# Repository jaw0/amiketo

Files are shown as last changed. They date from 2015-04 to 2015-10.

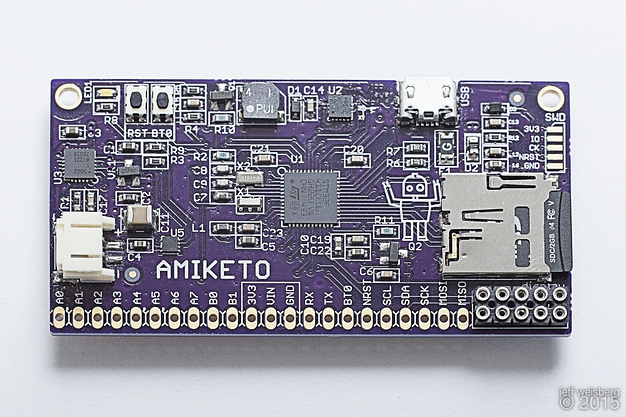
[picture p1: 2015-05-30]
img/64c068820_6_amiketo_top.jpg

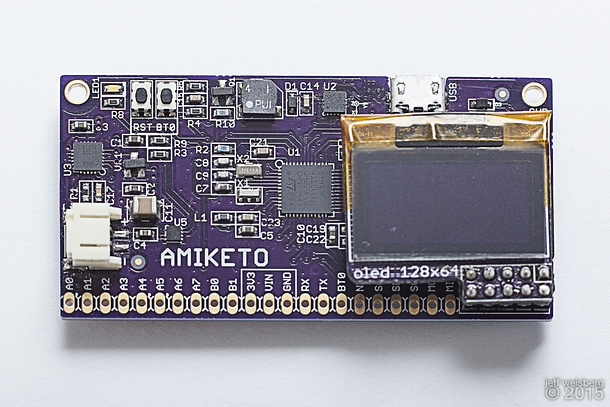
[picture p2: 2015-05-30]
img/64c068822_6_amiketo_oled.jpg

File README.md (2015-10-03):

tiny, low power, ARM-based board

* 35mm x 69mm
* breadboard friendly pinout

hardware:

* STM32F411
  * 96 MHz Cortex M4F
  * 100 uA / MHz
  * 10 analog inputs
  * 10 digital inputs
  * 10 digital outputs
  *  8 PWM outputs
  * i2c, spi, uart, usb
  * real-time-clock
  * board compat with most 48pin STM32s (eg. F103, L152, L072)
* micro SD card
* audio speaker
* OLED display
* AD5062 programmable battery charger
  * configurable charge current
  * configurable USB current
  * configurable charging parameters
* MAX17048 battery fuel gauge

software:

* can (will eventually) run open-source:
  * python
  * javascript
  * mbed
  * .NET
  * arduino
* comes with battery charger + data-logger
* write your own code

other:

* RoHS, lead-free
* fat-free, sugar-free, gluten-free

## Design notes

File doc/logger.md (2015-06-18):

## features

* depending on the config, logging 2 analog channels at audio rates is possible
* can programmatically control whether to log or not log
* wide variety of file formats
* log analog or digital values

## configuring the data logger

`logger_logfile = <filename>` - set the output file name

`logger_values <list of pins>` - specify which pins to log

`logger_format <format>` - specify the data file format. currently supported:
* csv   - comma separated values
* json  - newline delimited json
* xml   - record oriented, partial xml (missing outer wrapper)
* raw   - raw 16bit little-endian values
* sln   - raw signed-linear 16bit little-endian values
* alaw  - 8 bit a-law compressed
* xlaw  - 8 bit unsigned 3e/5m compressed
* bits  - raw 1 bit per value, for digital inputs
* tca   - a-law with timestamps + silence suppression

`logger_rate <rate>` - specify the logging sampling rate.
depending on your config, you may be able to go from
usecs to years.
suffix with `u` for microseconds, `m` for milliseconds,
`M` for minutes, `H` for hours, `D` for days.

`logger_lowpower = <0,1>` if set to 1, system will enter low-power standby mode
at slow sampling rates

`logger_script = <filename>` - specify a script to run at each sampling. script
can choose to log or not log the samples, or perform other actions.

`logger_autostart = <0,1>` - start the logger automaitically at boot

`logger_start` - manually start the logger

`logger_stop`  - stop the logger

`logger_reload` - reload logging parameters

`logger_rotate` - rotate the log file

## example
```
pinmode A0 adc
pinmode A1 adc
logger_values A0 A1
logger_rate 1m
logger_logfile = data.log
logger_format xml
logger_start
```

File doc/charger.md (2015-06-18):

## configuring the battery charger

`input_current <mA>` - set the maximum USB input current.
can be set from 100 to 2100 millamps. you should not set this
higher than 500 millamps unless you are supplying
power via a non-USB source via the Vin pin.

`charge_current <mA>` - set the battery charging current.
can be set from 50 to 1300 milliamps. set this to the value
recommended by your battery manufacturer, setting a higher value
may damage the battery.

`charge_status` - show the current charging status

## example
```
input_current 500
charge_current 200
```

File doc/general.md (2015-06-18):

## configuring

* connect to the board using a terminal emulator + either the USB port or via a FT232 (or similar) on the RX/TX pins
* enter commands
* enter `save` to save the config to the SD card
* `show run` will show the current running config
* `more config.rc` will show the saved config
* `help` or `help command` for help

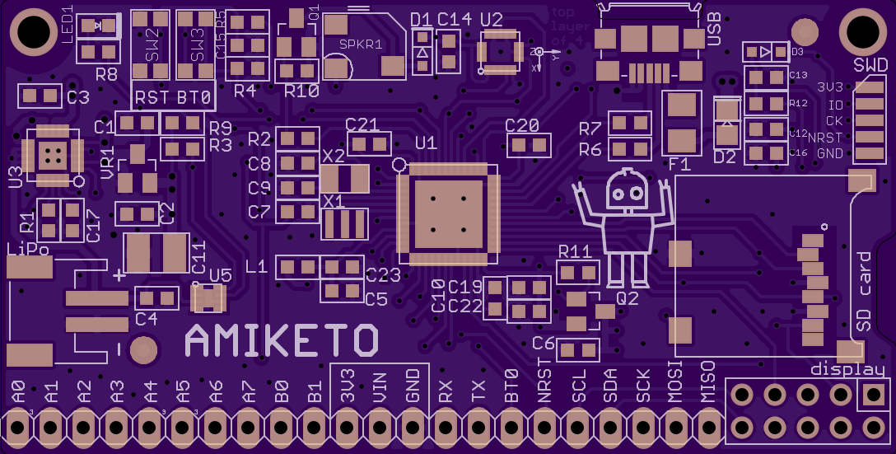
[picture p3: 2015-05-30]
img/pcb-top-oshpark.png

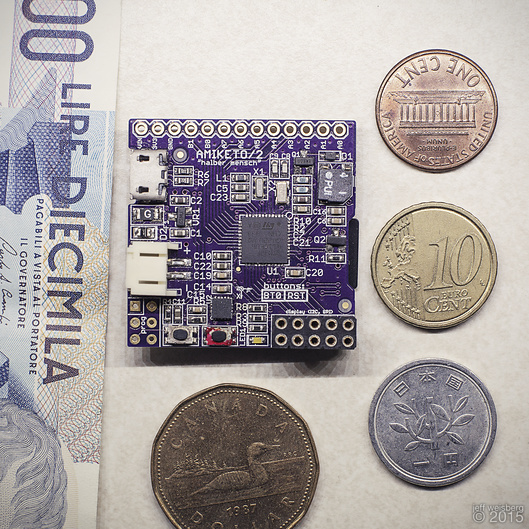
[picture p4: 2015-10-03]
img/money_for_scale.jpg

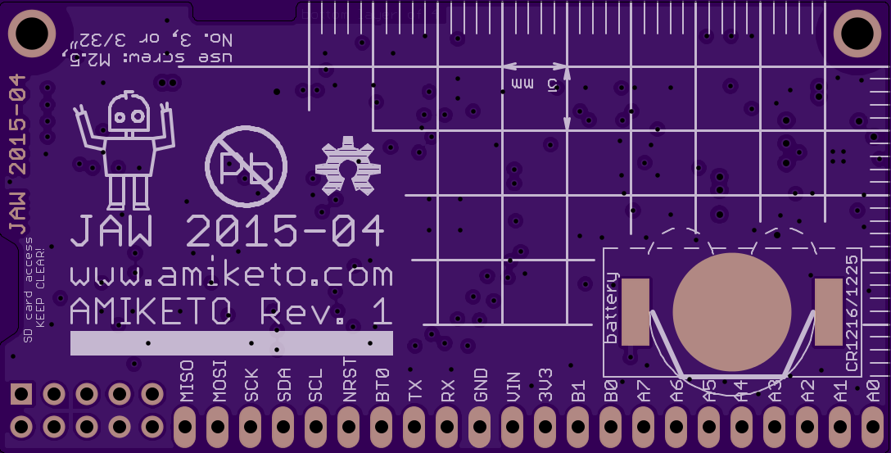
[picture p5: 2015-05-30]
img/pcb-bottom-oshpark.png

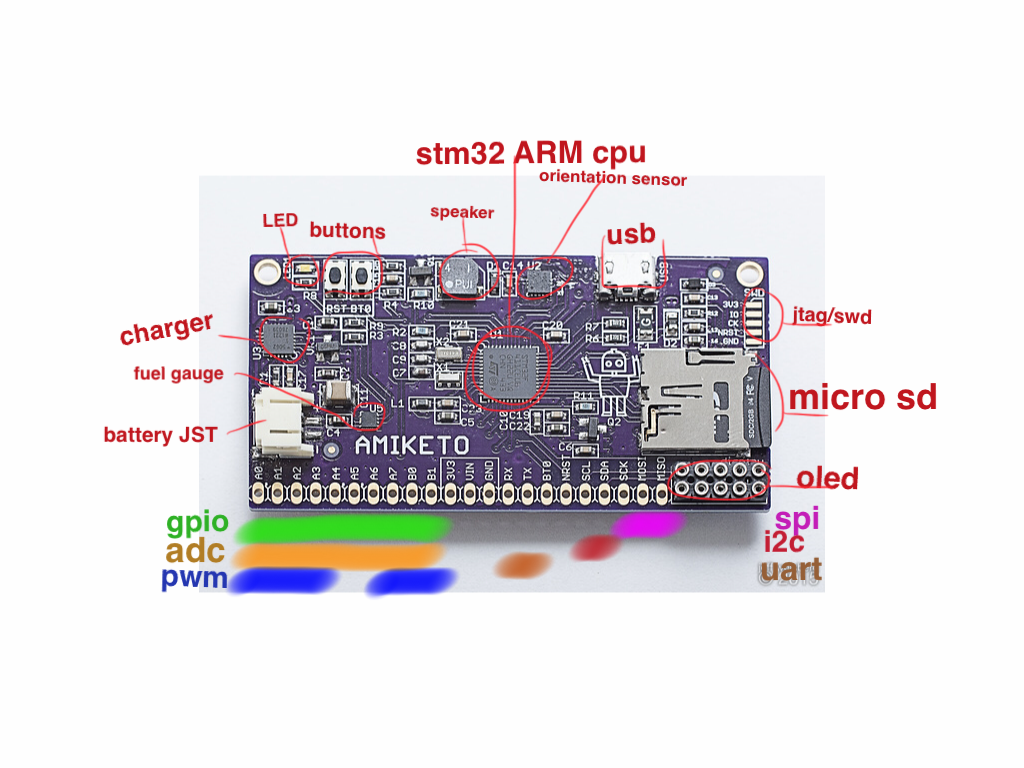
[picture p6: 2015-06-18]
img/board-labeled.png

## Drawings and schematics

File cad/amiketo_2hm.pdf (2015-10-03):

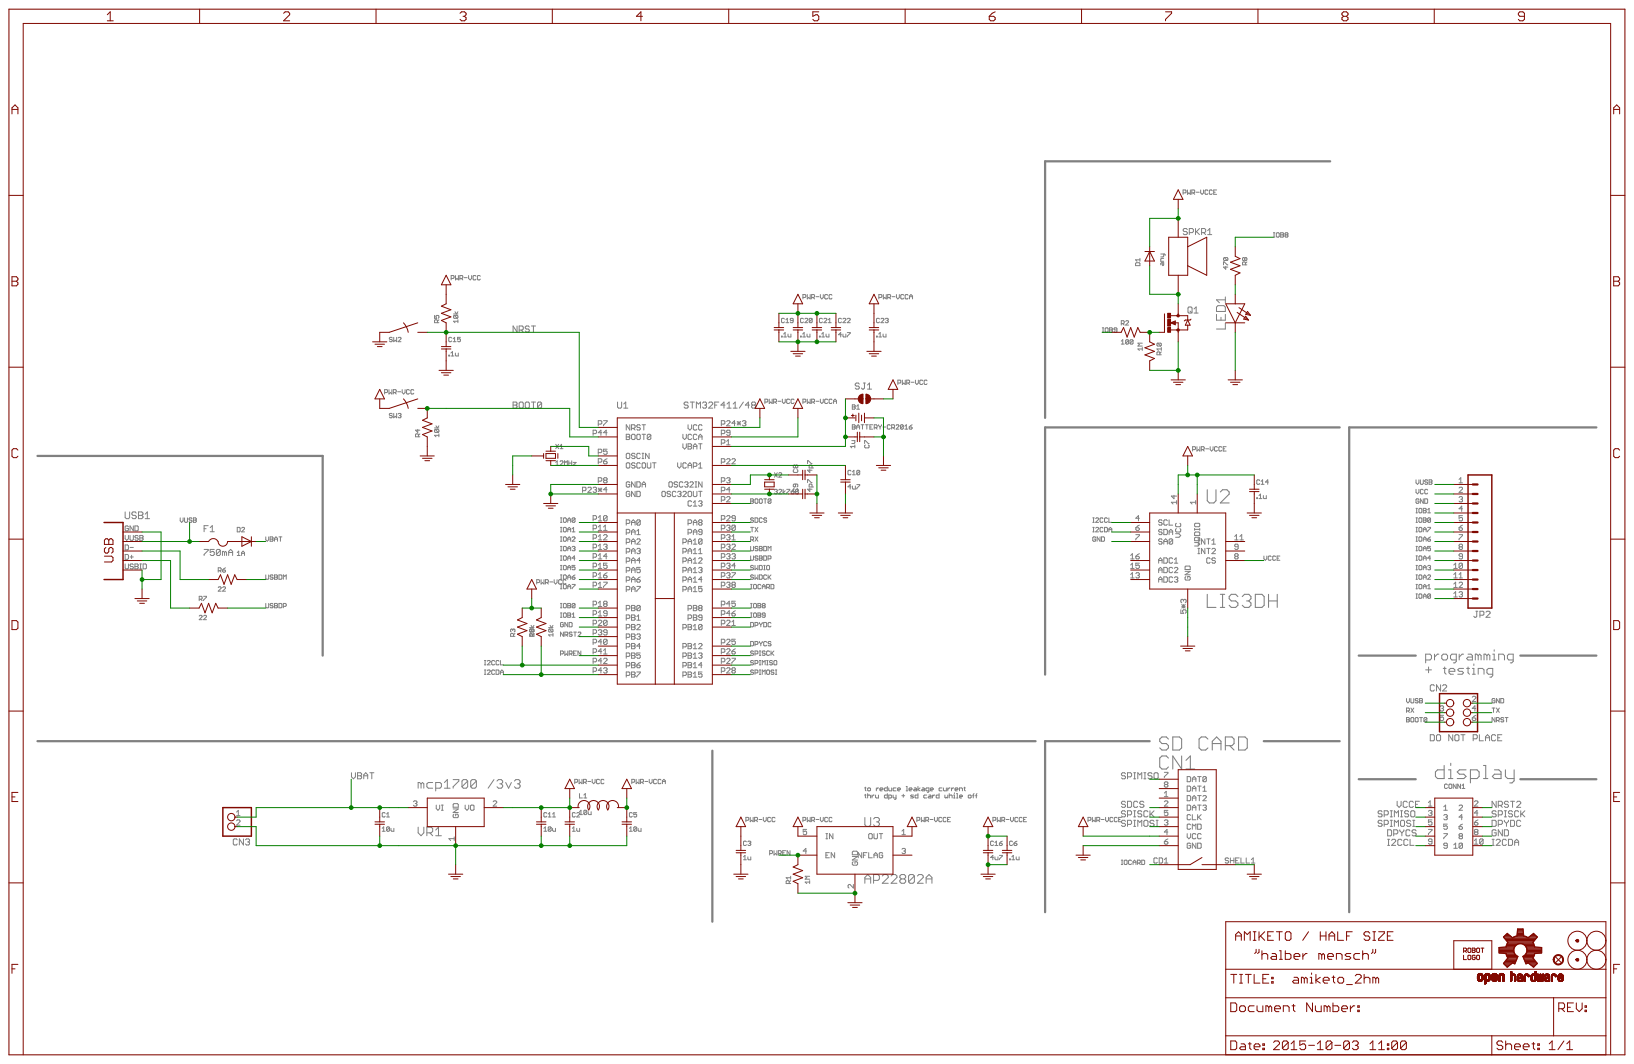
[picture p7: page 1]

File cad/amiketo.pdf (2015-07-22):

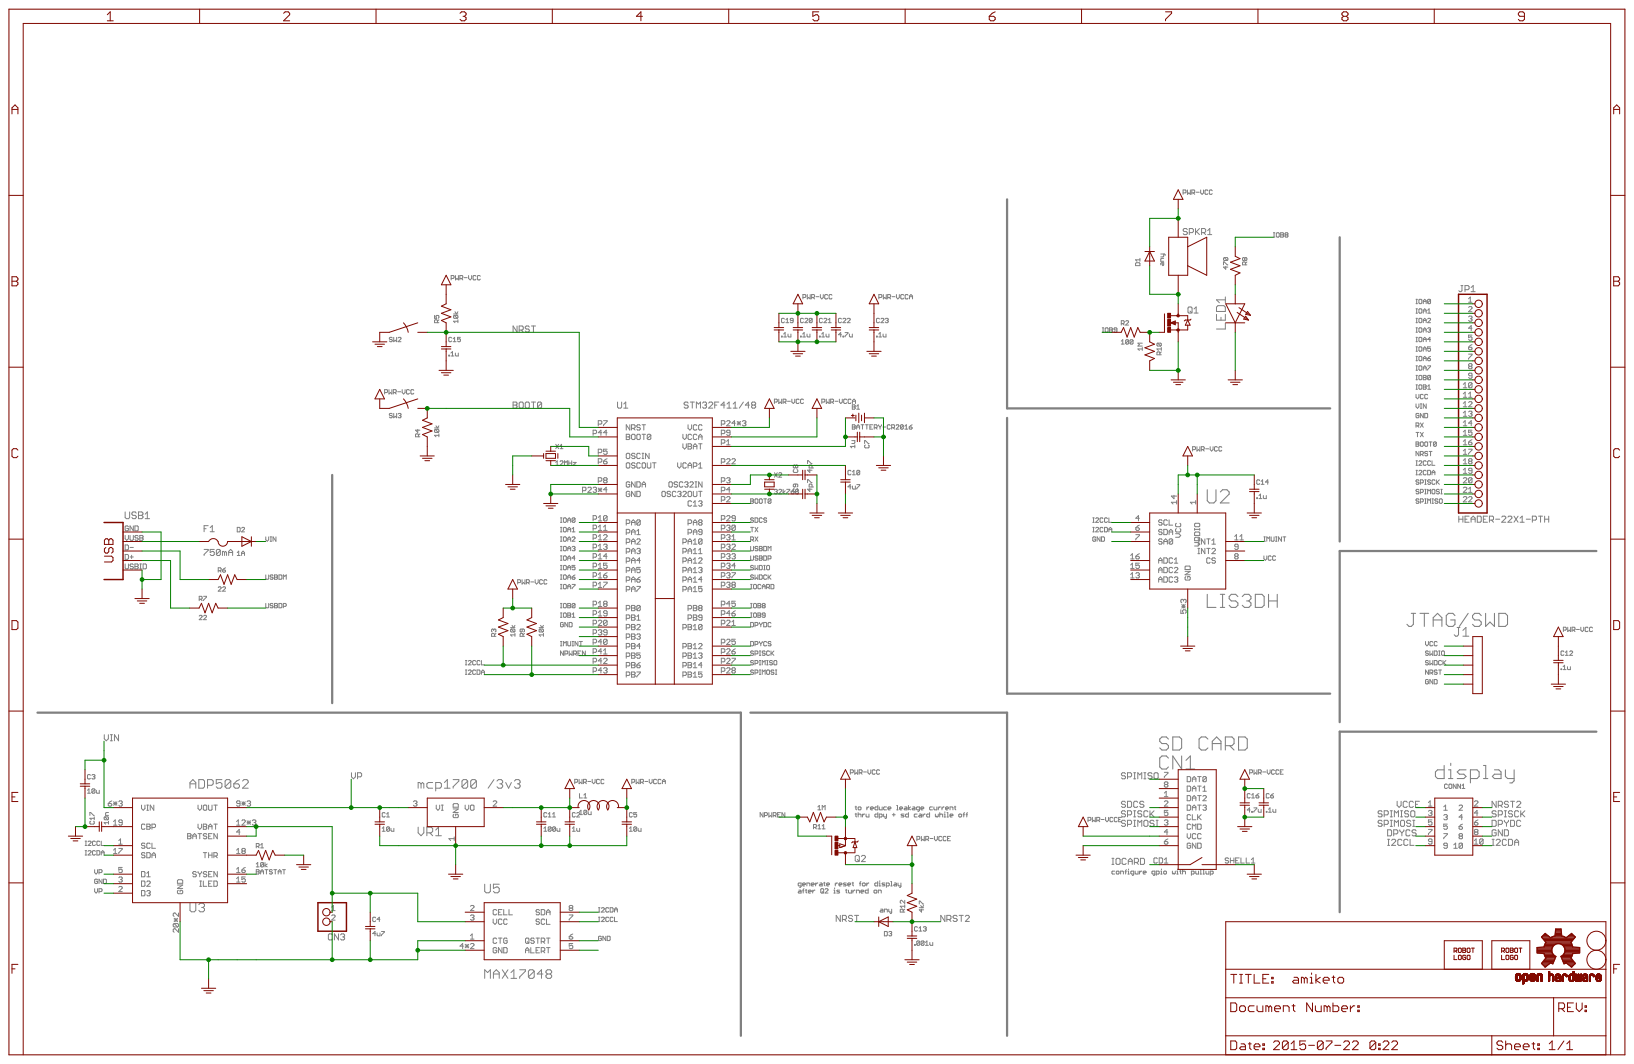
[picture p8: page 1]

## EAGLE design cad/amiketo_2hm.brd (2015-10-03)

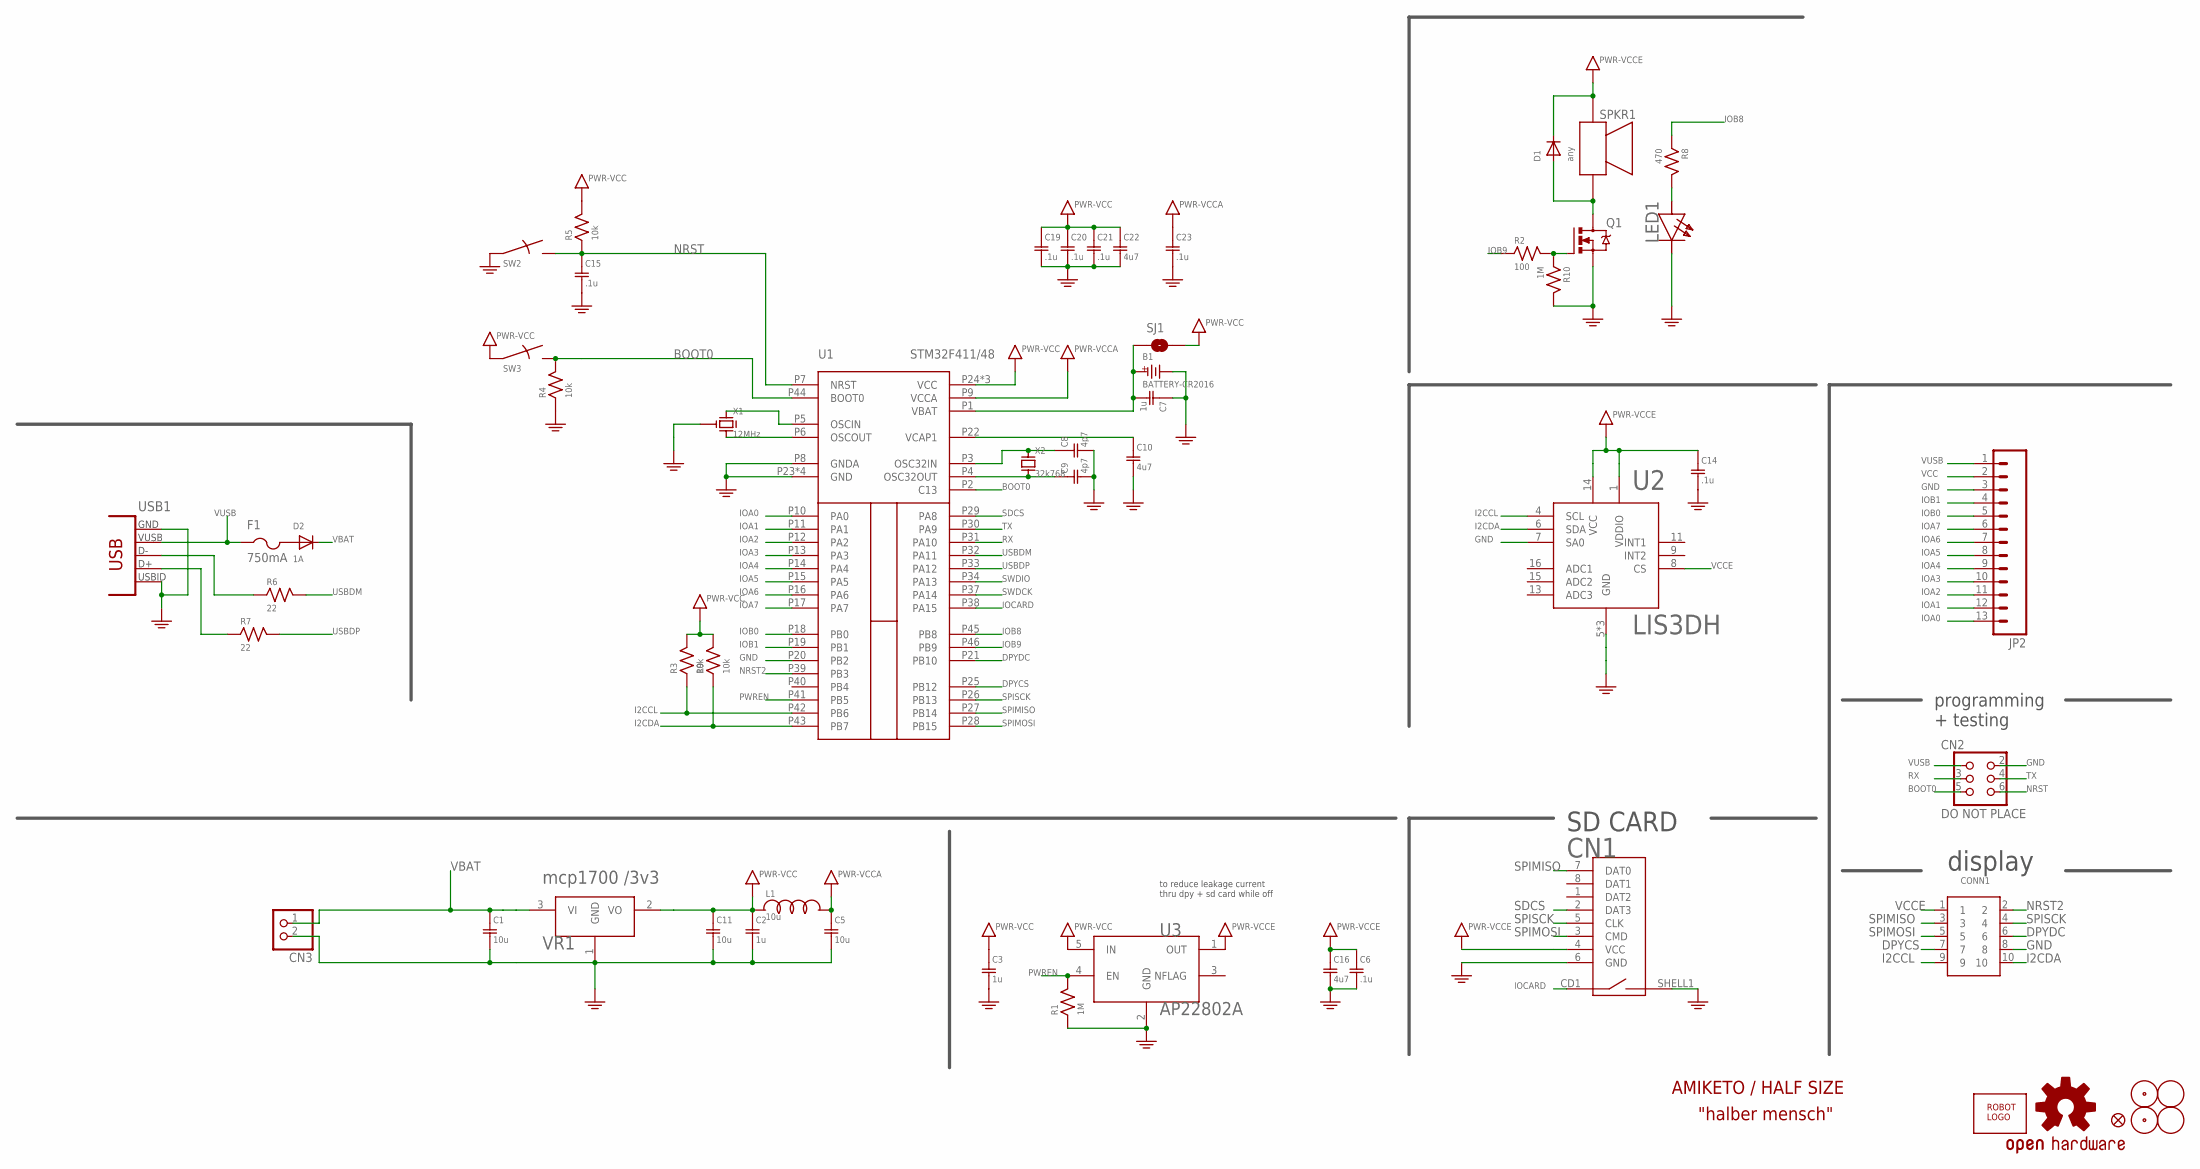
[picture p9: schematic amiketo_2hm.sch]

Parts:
B1: BATTERY-CR2016; CR1216
C1, C5, C11: 10u; SMD0603
C2, C3, C7: 1u; SMD0603
C6, C14, C15, C19, C20, C21, C23: .1u; SMD0603
C8, C9: 4p7; SMD0603
C10, C16, C22: 4u7; SMD0603
CN1: MICROSD-EJECT; MICROSD/EJECTOR
CN2: DO NOT PLACE; HEADER-3X2-POGO
CN3: JST_2PIN-SMT-RA; JST-PH-2-SMT-RA
CONN1: HEADER-5X2-PTH
D1: any; SMD0805D
D2: 1A; SMD0805D
F1: 750mA; SMD1206
JP2: M13; 1X13
L1: 10u; SMD0603
LED1: white; SMD0603D
LOGO1: OSHW-LOGOM; OSHW-LOGO-M
Q1: IRLML6344TRPBF; SOT-23
R1, R10: 1M; SMD0603
R2: 100; SMD0603
R3, R4, R5, R9: 10k; SMD0603
R6, R7: 22; SMD0603
R8: 470; SMD0603
SJ1: JUMPER-PAD-2-NOYES_SILK; PAD-JUMPER-2-NO_YES_SILK
SPKR1: PUI-5040; PUI-0540
SW2, SW3: SWITCHKMR211; KMR211
U1: STM32F411/48; UQPFN48
U2: LIS3DH; LGA16A
U3: AP22802A; SOT-23-5
U$1, U$5: FIDUCIAL
U$2, U$3: FIDUCIAL; FIDUCIAL_1MM
U$4: ROBOTMAN-LOGO2
U$6: FIDUCIALUFIDUCIAL; MICRO-FIDUCIAL
USB1: CON-USB-F-MICRO-B; CONN_USB_MICRO-B
VR1: mcp1700 /3v3; SOT-23-3
X1: 12MHz; RESONATOR-CSTCE
X2: 32k768; XTAL-32X15

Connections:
BOOT0: CN2.5, R4.2, SW3.2, SW3.4, U1.P2 (C13), U1.P44 (BOOT0)
DPYCS: CONN1.7, U1.P25 (PB12)
DPYDC: CONN1.6, U1.P21 (PB10)
GND: B1.MINUS (M), C1.2, C2.2, C3.2, C5.2, C6.2, C7.1, C8.2, C9.2, C10.2, C11.2, C14.2, C15.2, C16.2, C19.2, C20.2, C21.2, C22.2, C23.2, CN1.6 (GND), CN1.SHELL1 (SW2), CN2.2, CN3.2 (1), CONN1.8, JP2.3, LED1.C, Q1.2 (S), R1.1, R4.1, R10.2, SW2.1, SW2.3, U1.P8 (GNDA), U1.P20 (PB2), U1.P23 (GND), U1.P35 (GND), U1.P47 (GND), U1.PAD (GND), U2.5 (GND), U2.7 (SA0), U2.10 (GND), U2.12 (GND), U3.2 (GND), USB1.P4 (USBID), USB1.P5 (GND), VR1.1 (GND), X1.2 (G)
I2CCL: CONN1.9, R3.1, U1.P42 (PB6), U2.4 (SCL)
I2CDA: CONN1.10, R9.1, U1.P43 (PB7), U2.6 (SDA)
IOA0: JP2.13, U1.P10 (PA0)
IOA1: JP2.12, U1.P11 (PA1)
IOA2: JP2.11, U1.P12 (PA2)
IOA3: JP2.10, U1.P13 (PA3)
IOA4: JP2.9, U1.P14 (PA4)
IOA5: JP2.8, U1.P15 (PA5)
IOA6: JP2.7, U1.P16 (PA6)
IOA7: JP2.6, U1.P17 (PA7)
IOB0: JP2.5, U1.P18 (PB0)
IOB1: JP2.4, U1.P19 (PB1)
IOB8: R8.1, U1.P45 (PB8)
IOB9: R2.1, U1.P46 (PB9)
IOCARD: CN1.CD1 (SW1), U1.P38 (PA15)
unnamed: R6.1, USB1.P2 (D-)
unnamed: R7.1, USB1.P3 (D+)
unnamed: Q1.1 (G), R2.2, R10.1
unnamed: LED1.A, R8.2
unnamed: U1.P5 (OSCIN), X1.1 (X1)
unnamed: U1.P6 (OSCOUT), X1.3 (X2)
unnamed: D1.A, Q1.3 (D), SPKR1.P2
unnamed: C8.1, U1.P3 (OSC32IN), X2.P$1
unnamed: C9.1, U1.P4 (OSC32OUT), X2.P$2
unnamed: C10.1, U1.P22 (VCAP1)
unnamed: B1.PLUS1, B1.PLUS2, C7.2, SJ1.1, U1.P1 (VBAT)
unnamed: D2.A, F1.2
NRST: C15.1, CN2.6, R5.1, SW2.2, SW2.4, U1.P7 (NRST)
NRST2: CONN1.2, U1.P39 (PB3)
PWREN: R1.2, U1.P41 (PB5), U3.4 (EN)
RX: CN2.3, U1.P31 (PA10)
SDCS: CN1.2 (DAT3), U1.P29 (PA8)
SPIMISO: CN1.7 (DAT0), CONN1.3, U1.P27 (PB14)
SPIMOSI: CN1.3 (CMD), CONN1.5, U1.P28 (PB15)
SPISCK: CN1.5 (CLK), CONN1.4, U1.P26 (PB13)
SWDCK: U1.P37 (PA14)
SWDIO: U1.P34 (PA13)
TX: CN2.4, U1.P30 (PA9)
USBDM: R6.2, U1.P32 (PA11)
USBDP: R7.2, U1.P33 (PA12)
VBAT: C1.1, CN3.1 (2), D2.C, VR1.3 (VI)
VCC: C2.1, C3.1, C11.1, C19.1, C20.1, C21.1, C22.1, JP2.2, L1.1, R3.2, R5.2, R9.2, SJ1.2, SW3.1, SW3.3, U1.P24 (VCC), U1.P36 (VCC), U1.P48 (VCC), U3.5 (IN), VR1.2 (VO)
VCCA: C5.1, C23.1, L1.2, U1.P9 (VCCA)
VCCE: C6.1, C14.1, C16.1, CN1.4 (VCC), CONN1.1, D1.C, SPKR1.P1, U2.1 (VDDIO), U2.8 (CS), U2.14 (VCC), U3.1 (OUT)
VUSB: CN2.1, F1.1, JP2.1, USB1.P1 (VUSB)

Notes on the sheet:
SD CARD
display
to reduce leakage current thru dpy + sd card while off
programming + testing
AMIKETO / HALF SIZE
"halber mensch"

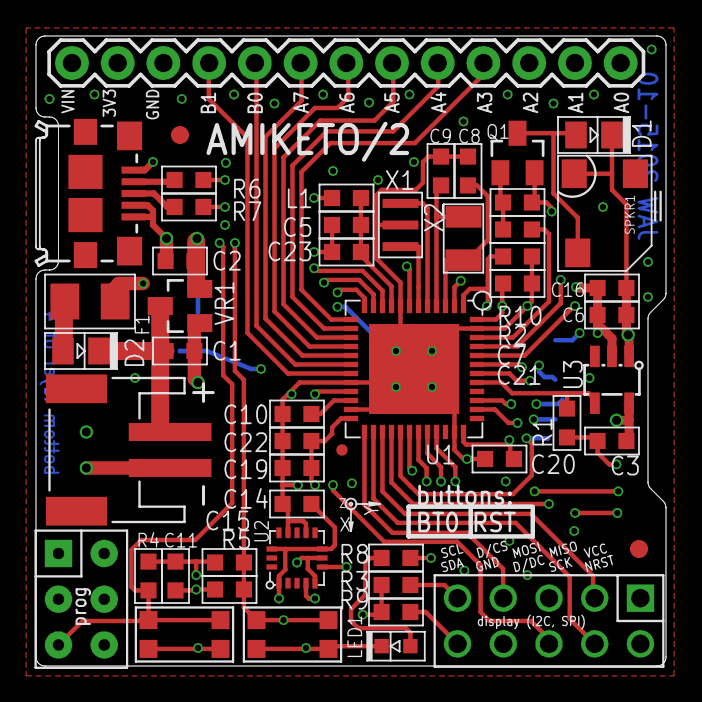
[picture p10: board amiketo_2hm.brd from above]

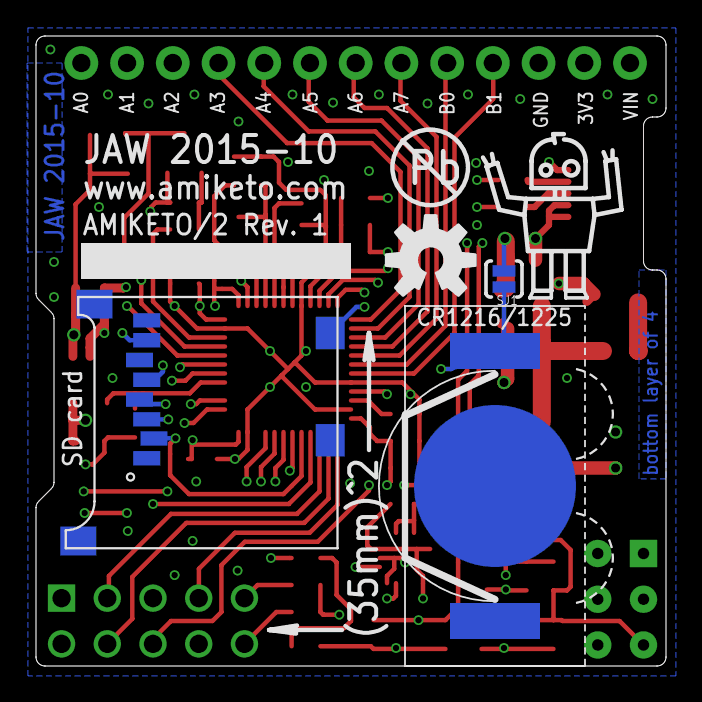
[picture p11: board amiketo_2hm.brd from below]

Board: 4 copper layers, 35.0 x 35.0 mm, 58 parts (7 on the bottom side), 47 nets.

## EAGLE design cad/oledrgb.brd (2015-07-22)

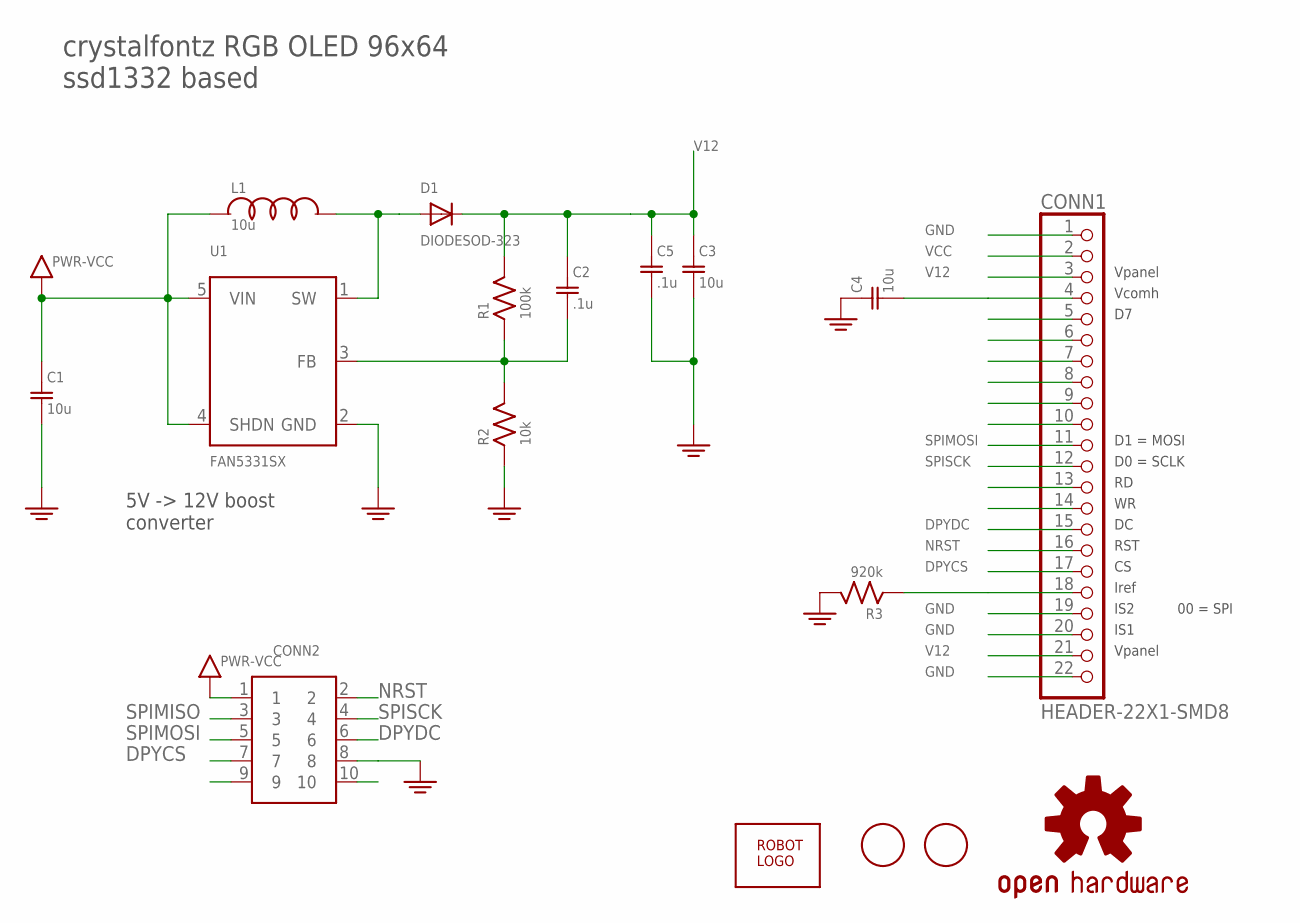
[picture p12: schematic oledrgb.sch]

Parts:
C1, C3, C4: 10u; SMD0603
C2, C5: .1u; SMD0603
CONN1: HEADER-22X1-SMD8
CONN2: HEADER-5X2-PTH
D1: DIODESOD-323; SOD-323
L1: 10u; SMD0603
LOGO1: OSHW-LOGOS; OSHW-LOGO-S
R1: 100k; SMD0603
R2: 10k; SMD0603
R3: 920k; SMD0603
U1: FAN5331SX; SOT23-5
U$1: ROBOTMAN-LOGO2
U$2, U$3: FIDUCIAL; FIDUCIAL_1MM

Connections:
DPYCS: CONN1.17, CONN2.7
DPYDC: CONN1.15, CONN2.6
GND: C1.2, C3.2, C4.1, C5.2, CONN1.1, CONN1.19, CONN1.20, CONN1.22, CONN2.8, R2.1, R3.2, U1.2 (GND)
unnamed: D1.A, L1.2, U1.1 (SW)
unnamed: C2.2, R1.1, R2.2, U1.3 (FB)
unnamed: C4.2, CONN1.4
unnamed: CONN1.18, R3.1
NRST: CONN1.16, CONN2.2
SPIMISO: CONN2.3
SPIMOSI: CONN1.11, CONN2.5
SPISCK: CONN1.12, CONN2.4
V12: C2.1, C3.1, C5.1, CONN1.3, CONN1.21, D1.C, R1.2
VCC: C1.1, CONN1.2, CONN2.1, L1.1, U1.4 (SHDN), U1.5 (VIN)

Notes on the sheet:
Vpanel
Vcomh
D0 = SCLK
D1 = MOSI
RST
Iref
IS2
IS1
00 = SPI
crystalfontz RGB OLED 96x64 ssd1332 based
5V -> 12V boost converter

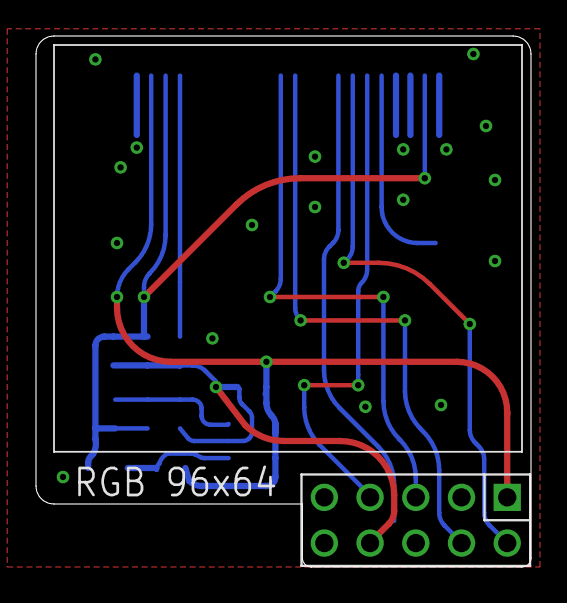
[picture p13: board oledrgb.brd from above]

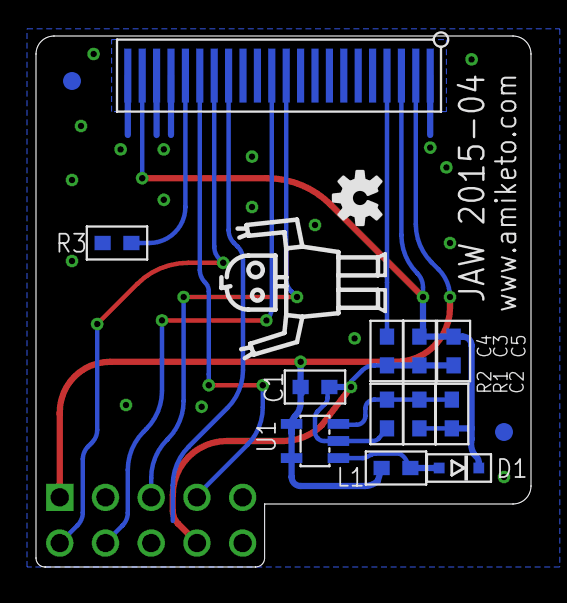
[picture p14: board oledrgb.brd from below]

Board: 2 copper layers, 27.5 x 29.5 mm, 17 parts (16 on the bottom side), 12 nets.

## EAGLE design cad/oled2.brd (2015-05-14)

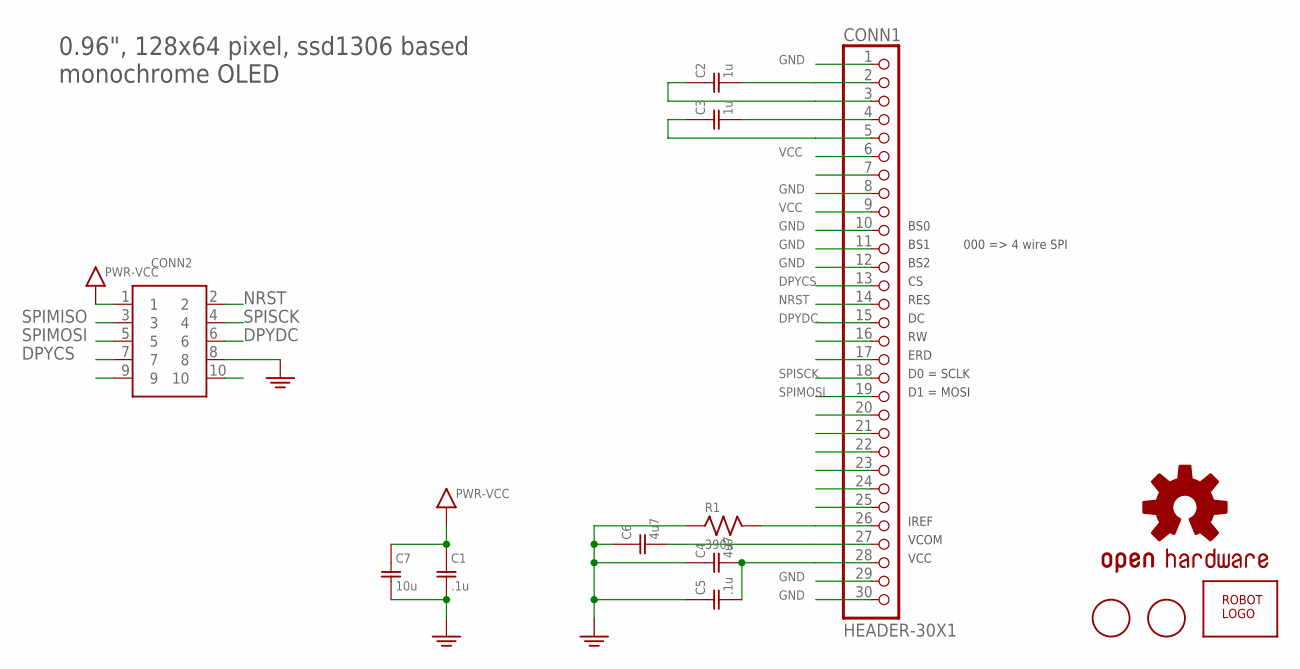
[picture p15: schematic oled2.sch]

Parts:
C1, C5: .1u; SMD0603
C2, C3: 1u; SMD0603
C4, C6: 4u7; SMD0603
C7: 10u; SMD0603
CONN1: HEADER-30X1; HEADER-30X1-SMD7
CONN2: HEADER-5X2-PTH
LOGO1: OSHW-LOGOS; OSHW-LOGO-S
R1: 390k; SMD0603
U$1, U$2: FIDUCIAL; FIDUCIAL_1MM
U$3: ROBOTMAN-LOGO2

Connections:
DPYCS: CONN1.13, CONN2.7
DPYDC: CONN1.15, CONN2.6
GND: C1.2, C4.1, C5.1, C6.1, C7.2, CONN1.1, CONN1.8, CONN1.10, CONN1.11, CONN1.12, CONN1.29, CONN1.30, CONN2.8, R1.1
unnamed: C2.2, CONN1.2
unnamed: C2.1, CONN1.3
unnamed: C3.2, CONN1.4
unnamed: C3.1, CONN1.5
unnamed: CONN1.26, R1.2
unnamed: C6.2, CONN1.27
unnamed: C4.2, C5.2, CONN1.28
NRST: CONN1.14, CONN2.2
SPIMISO: CONN2.3
SPIMOSI: CONN1.19, CONN2.5
SPISCK: CONN1.18, CONN2.4
VCC: C1.1, C7.1, CONN1.6, CONN1.9, CONN2.1

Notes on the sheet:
BS0
BS1
BS2
000 => 4 wire SPI
RES
ERD
D0 = SCLK
D1 = MOSI
IREF
VCOM
VCC
0.96", 128x64 pixel, ssd1306 based monochrome OLED

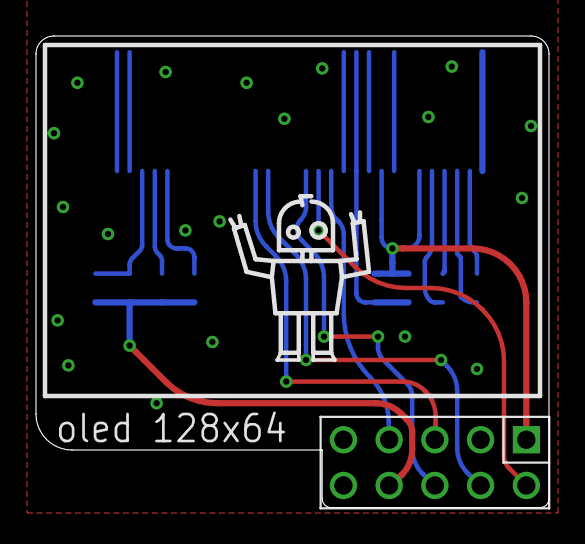
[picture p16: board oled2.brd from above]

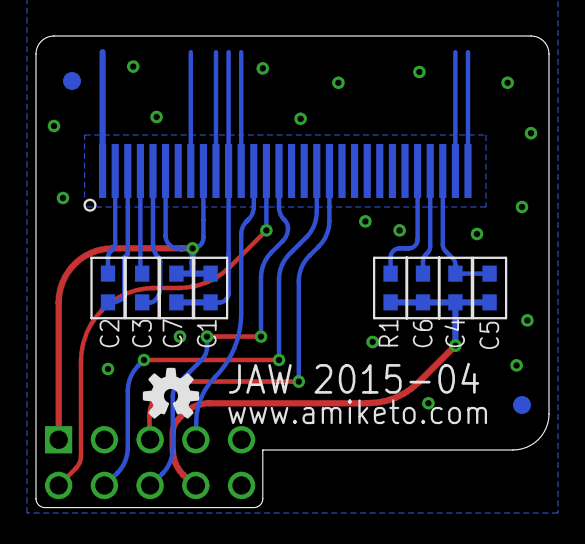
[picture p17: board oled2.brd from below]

Board: 2 copper layers, 28.5 x 26.2 mm, 14 parts (12 on the bottom side), 14 nets.

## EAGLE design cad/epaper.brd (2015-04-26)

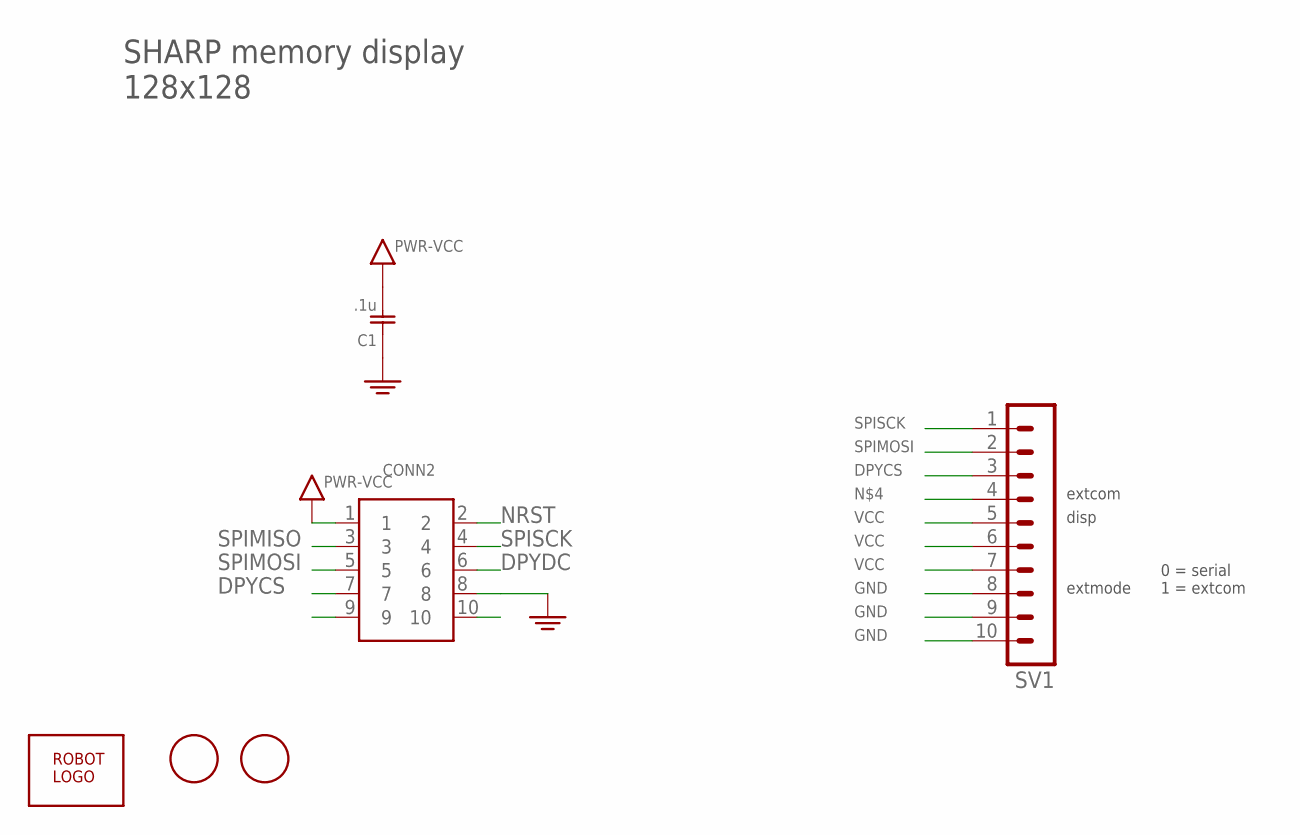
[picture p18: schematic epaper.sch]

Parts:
C1: .1u; SMD0603
CONN2: HEADER-5X2-PTH
SV1: MA10-1-M05/FFC; M05-1X10-RA
U$1: ROBOTMAN-LOGO2
U$2, U$3: FIDUCIAL; FIDUCIAL_1MM

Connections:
DPYCS: CONN2.7, SV1.3
DPYDC: CONN2.6
GND: C1.1, CONN2.8, SV1.8, SV1.9, SV1.10
NRST: CONN2.2
SPIMISO: CONN2.3
SPIMOSI: CONN2.5, SV1.2
SPISCK: CONN2.4, SV1.1
VCC: C1.2, CONN2.1, SV1.5, SV1.6, SV1.7

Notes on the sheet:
SHARP memory display 128x128
extcom
extmode
disp
0 = serial 1 = extcom

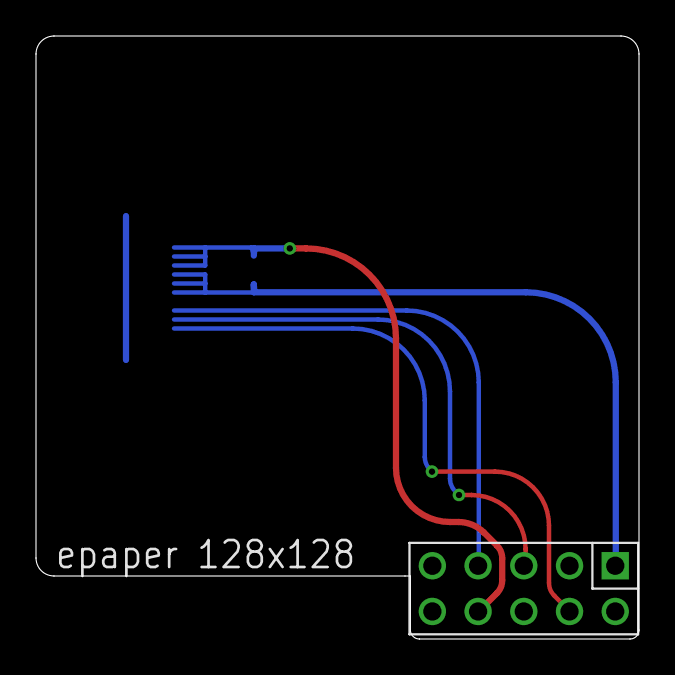
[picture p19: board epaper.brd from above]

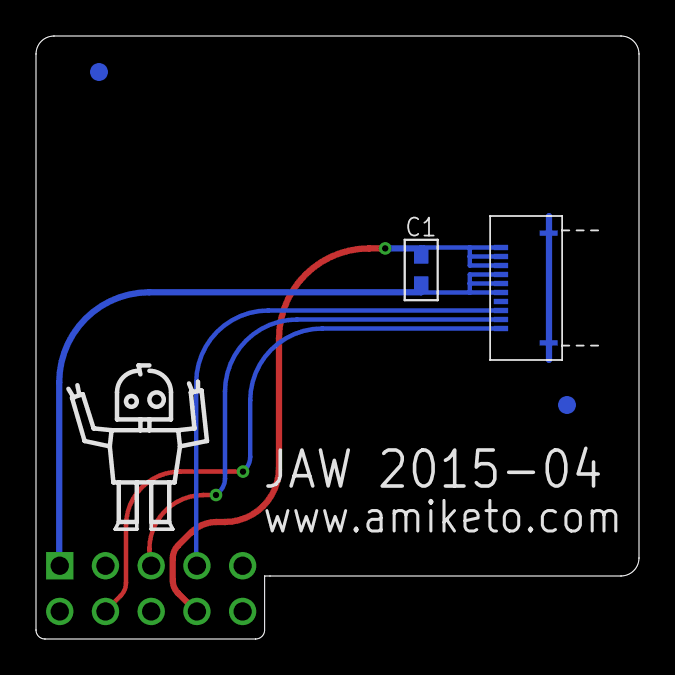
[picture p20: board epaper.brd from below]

Board: 2 copper layers, 33.5 x 33.5 mm, 6 parts (5 on the bottom side), 5 nets.

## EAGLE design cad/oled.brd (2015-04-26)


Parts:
C1: .1u; SMD0603
CN2: MA12-1; M05-1X12-RA
CONN2: HEADER-5X2-PTH
U$1, U$2: FIDUCIAL; FIDUCIAL_1MM

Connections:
DPYCS: CN2.P7, CONN2.7
DPYDC: CN2.P5, CONN2.6
GND: C1.2, CN2.P1, CN2.P8, CN2.P9, CN2.P12, CONN2.8
NRST: CN2.P6, CONN2.2
SPIMISO: CONN2.3
SPIMOSI: CN2.P3, CONN2.5
SPISCK: CN2.P4, CONN2.4
VCC: C1.1, CN2.P10, CN2.P11, CONN2.1

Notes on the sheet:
P8,P9 = BS0,BS1 => 4wire SPI (CFAL docs say 11, SSD says 00)
crystalfontz 128x32 OLED



Board: 2 copper layers, 17.1 x 21.5 mm, 5 parts (4 on the bottom side), 7 nets.

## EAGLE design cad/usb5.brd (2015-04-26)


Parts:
C1: 2.2u; SMD0603
C2: 1u; SMD0603
CN2: CON_HEADER_1X04; M1X4
D1: DIODESOD-323; SOD-323
LED1: GREEN; SMD0603D
LED2: ORANGE; SMD0603D
R1: 270; SMD0603
R2: 560; SMD0603
U8: IC_FT230X-SSOP-16; SSOP-16-FTDI
U$1: ROBOTMAN-LOGO2
USB1: CON-USB-F-MICRO-B; CONN_USB_MICRO-B

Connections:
GND: C1.2, C2.2, CN2.2, U8.5 (GND), U8.13 (GND), USB1.P4 (USBID), USB1.P5 (GND)
unnamed: CN2.1, D1.C
unnamed: U8.8 (USB+), USB1.P3 (D+)
unnamed: U8.9 (USB-), USB1.P2 (D-)
unnamed: LED1.C, R1.2
unnamed: LED2.C, R2.2
unnamed: R1.1, U8.14 (CBUS1)
unnamed: R2.1, U8.7 (CBUS2)
RXD: CN2.3, U8.1 (TXD)
TXD: CN2.4, U8.4 (RXD)
USB3V3: C1.1, LED1.A, LED2.A, U8.3 (VCCIO), U8.10 (3V3OUT), U8.11 (!RESET)
VBUS: C2.1, D1.A, U8.12 (VCC), USB1.P1 (VUSB)


Board: 2 copper layers, 22.5 x 14.5 mm, 11 parts (1 on the bottom side), 12 nets.

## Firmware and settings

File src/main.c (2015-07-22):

/*
  Copyright (c) 2015
  Author: Jeff Weisberg <jaw @ tcp4me.com>
  Created: 2015-Apr-02 21:37 (EDT)
  Function: 

*/

#include <conf.h>
#include <proc.h>
#include <gpio.h>
#include <pwm.h>
#include <adc.h>
#include <spi.h>
#include <i2c.h>
#include <ioctl.h>
#include <error.h>
#include <stm32.h>
#include <userint.h>

#include "util.h"


#define FLASHSTART	0x08000000
extern const u_char* _etext;

extern void blinky(void);

// first look on the card, then flash
// NB: if we check the flash first, a bad config could brick the system
#define RUN_SCRIPT(file)        (run_script("sd0:" file) && run_script("fl0:" file))

DEFVAR(int, dpy_ui_enable,    1, UV_TYPE_UL | UV_TYPE_CONFIG, "run user-interface on display")
DEFVAR(int, serial_enable,    1, UV_TYPE_UL | UV_TYPE_CONFIG, "run shell on serial")
DEFVAR(int, logger_autostart, 1, UV_TYPE_UL | UV_TYPE_CONFIG, "start logger automatically at boot")

DEFUN(save, "save all config data")
{
    // save_config("fl0:config.rc");
    save_config("config.rc");
    return 0;
}


// make sure we have 2 copies of the file (on card + on flash)
static void
two_copies(const char *file){
    char bufc[128];
    char buff[128];
    FILE *f1, *f2;

    snprintf(bufc, sizeof(bufc), "sd0:%s", file);
    snprintf(buff, sizeof(bufc), "fl0:%s", file);

    f1 = fopen(buff, "r");
    f2 = fopen(bufc, "r");
    if( f1 ) fclose(f1);
    if( f2 ) fclose(f2);

    if( f1 && f2 )   return;    // all good.
    if( !f1 && !f2 ) return;    // all bad.

    if( f1 ){
        // copy fl -> sd
        f1 = fopen(buff, "r");
        f2 = fopen(bufc, "w");
    }else{
        // copy sd -> fl
        f1 = fopen(bufc, "r");
        f2 = fopen(buff, "w");
    }
    if( !f1 || !f2 ){
        // open failed - probably no card
        if( f1 ) fclose(f1);
        if( f2 ) fclose(f2);
        return;
    }

    int i;
    while( (i=fread(f1, bufc, sizeof(bufc))) > 0 ){
        fwrite(f2, bufc, i);
    }

    fclose(f1);
    fclose(f2);
}

unsigned int
random(void){
    static unsigned int x;
    unsigned int y;

    y = RTC->SSR ^ RTC->TR;
    y ^= RTC->DR;
    y ^= SysTick->VAL;

    x = (x<<7) | (x>>25);
    x ^= y;
    return x ^ lrand48();
}


#if defined(USE_SSD1306)
#  define dpy_puts	ssd13060_puts
#elif defined(USE_SSD1331)
#  define dpy_puts	ssd13310_puts
#elif defined(USE_EPAPER)
#  define dpy_puts	epaper0_puts
#endif


// on panic: beep, flash, and display message
// NB: system will also output to the console
void
onpanic(const char *msg){
    int i;

    set_led_white( 0xFF );
    beep_set(200, 127);

    splproc();
    currproc = 0;

    dpy_puts("\e[J\e[16m*** PANIC ***\r\n\e[15m");
    if( msg ){
        dpy_puts(msg);
        dpy_puts("\r\n");
    }
    splhigh();

    while(1){
        set_led_white( 0xFF );
        beep_set(150, 127);
        for(i=0; i<5000000; i++){ asm("nop"); }
        set_led_white( 0x1F );
        beep_set(250, 127);
        for(i=0; i<5000000; i++){ asm("nop"); }
    }
}

void
set_onwake(int val){
    RTC->BKP1R = val;
}

//################################################################

// put all peripherals in their lowest power mode
// put the processor into "standby" mode

void
shutdown(void){
    kprintf("powering down\n");
    ui_sleep();
    board_disable();
    power_down();
}


DEFUN(shutdown, "shut down system")
DEFALIAS(shutdown, poweroff)
DEFALIAS(shutdown, halt)
{
    shutdown();
    return 0;
}


//################################################################

extern const struct Menu guitop;

void
uiproc(void){
    FILE *f = fopen("dev:oled0", "w");
    STDOUT = f;
    STDIN  = 0;

    usleep( 100000 );

    menu( &guitop );
}


void
serproc(void){
    FILE *f = fopen("dev:serial0", "w");
    STDOUT = f;
    STDIN  = f;
    STDERR = f;

    usleep( 100000 );
    shell();
}

//################################################################


// use rtc reg for mode

void
main(void){

    board_init();
    RUN_SCRIPT("config.rc");

    // is this a reset or wakeup?
    // wakeup + logger mode => log once + power down

    if( was_rtc_wakeup() ){
        RUN_SCRIPT("wakeup.rc");

        int onwake = RTC->BKP1R;
        set_onwake( 0 );
        if( onwake > FLASHSTART && onwake < (int)&_etext ){
            void (*func)(void) = (void(*)(void))onwake;
            func();
        }
    }

    set_onwake( 0 );
    set_led_white( 0xFF );	// flash LED
    board_init2();
    set_led_white( 0x3F );

    play(6, "g4g4g4f4z4a4g2");
    RUN_SCRIPT("startup.rc");

    while( check_button() ){
        usleep(1000);
    }

    set_led_white( 0 );
    start_proc(512, blinky, "blinky");

    if( dpy_ui_enable )
        start_proc(2048, uiproc, "ui");

    if( serial_enable )
        start_proc(2048, serproc, "shell");

    if( logger_autostart )
        logger_init();

    printf("\n");

}

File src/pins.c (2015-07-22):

/*
  Copyright (c) 2015
  Author: Jeff Weisberg <jaw @ tcp4me.com>
  Created: 2015-Apr-05 10:05 (EDT)
  Function: configure pins, etc

*/

#include <conf.h>
#include <proc.h>
#include <stm32.h>
#include <nvic.h>
#include <gpio.h>
#include <adc.h>
#include <pwm.h>
#include <userint.h>

#include "util.h"
#include "pins.h"

#define USE_ADCDMA

#define NUM_PINS	10


#ifdef USE_ADCDMA
static short dmabuf[16];
static int   dmasqr[3];
static int   adc_count;
static int   adc_acqmask;
static void adc_dma_sqr_init(int);
static void adc_dma_get_all(void);
#endif


struct pin_descr {
    const char *name;
    short       gpio;
    short       adc;
    short       timer;
    short	timeraf;
    short       dac;	// coming soon...
    short	touch;	// coming soon...
};
const struct pin_descr descr[] = {
    { "A0", GPIO_A0, ADC_1_0, TIMER_2_1, 1, -1, -1 },
    { "A1", GPIO_A1, ADC_1_1, TIMER_2_2, 1, -1, -1 },
    { "A2", GPIO_A2, ADC_1_2, TIMER_2_3, 1, -1, -1 },
    { "A3", GPIO_A3, ADC_1_3, TIMER_2_4, 1, -1, -1 },
    { "A4", GPIO_A4, ADC_1_4, -1,        0,  1, -1 },
    { "A5", GPIO_A5, ADC_1_5, -1,        0,  2, -1 }, // T8/1N
    { "A6", GPIO_A6, ADC_1_6, TIMER_3_1, 2, -1, -1 },
    { "A7", GPIO_A7, ADC_1_7, TIMER_3_2, 2, -1, -1 },
    { "B0", GPIO_B0, ADC_1_8, TIMER_3_3, 2, -1, -1 },
    { "B1", GPIO_B1, ADC_1_9, TIMER_4_4, 2, -1, -1 },

    // if the serial port is disabled
#ifndef USE_SERIAL
    { "A9",  GPIO_A9,  -1,      TIMER_1_2, 1, -1, -1 },
    { "A10", GPIO_A10, -1,      TIMER_1_3, 1, -1, -1 },
#endif
};


struct pin_config {
    short	mode;
    short	gpcf;
    short	adcsamp;
    short	pwmfreq;
    short	pwmmax;
};

struct pin_config config[NUM_PINS];

static const short sampletime[] = {
    3, 15, 28, 56, 84, 112, 144, 480
};

int
find_pin(const char *pin){
    short i;

    for(i=0; i<ELEMENTSIN(descr); i++){
        if( !strcasecmp(pin, descr[i].name) ) return i;
    }
    return -1;
}

int
best_sample_value(int samp){
    short i;

    for(i=0; i<ELEMENTSIN(sampletime); i++){
        if( sampletime[i] >= samp ) return i;
    }

    return ELEMENTSIN(sampletime) - 1;
}


// pinmode PIN MODE [...]
// pinmode A0 adc [samples 20]
// pinmode A0 pwm [freq 10000] [max 255]
// pinmode A0 input [pullup|pulldown]
// pinmode A0 output [pushpull|opendrain|pullup]

DEFUN(pinmode, "set pin mode")
{
    if( argc < 3 ){
        fprintf(STDERR, "error: pinmode pin mode [...]\n");
        return 0;
    }

    short p = find_pin(argv[1]);
    if( p == -1 ){
        fprintf(STDERR, "invalid pin '%s'\n", argv[1]);
        return 0;
    }

    if( !strcmp(argv[2], "none") ){
        gpio_init( descr[p].gpio, GPIO_INPUT );
        config[p].mode = PINMODE_NONE;
    }

    else if( !strcmp(argv[2], "input") ){
        short m = GPIO_INPUT;
        if( argc > 3 ){
            if( !strcmp(argv[3], "pullup") )   m |= GPIO_PULL_UP;
            if( !strcmp(argv[3], "pulldown") ) m |= GPIO_PULL_DN;
        }
        gpio_init( descr[p].gpio,  m );
        config[p].mode = PINMODE_IN;
        config[p].gpcf = m;
    }

    else if( !strcmp(argv[2], "output") ){
        short m = GPIO_OUTPUT | GPIO_SPEED_25MHZ;
        if( argc > 3 ){
            if( !strcmp(argv[3], "pushpull") )  m |= GPIO_PUSH_PULL;
            if( !strcmp(argv[3], "opendrain") ) m |= GPIO_OPEN_DRAIN;
            if( !strcmp(argv[3], "pullup") )    m |= GPIO_OPEN_DRAIN | GPIO_PULL_UP;
        }
        gpio_init( descr[p].gpio,  m );
        config[p].mode = PINMODE_OUT;
        config[p].gpcf = m;
    }

    else if( !strcmp(argv[2], "adc") ){
        if( descr[p].adc == -1 ){
            fprintf(STDERR, "adc not supported on pin %s\n", argv[1]);
            return 0;
        }
        short m = GPIO_ANALOG;
        short s = 1;

        // QQQ - or specify the circuit impedance?
        if( argc > 4 && !strcmp(argv[3], "samples") ) s = best_sample_value( atoi( argv[4] ) );
        gpio_init( descr[p].gpio,  m );
        adc_init( descr[p].adc, s );
        config[p].mode = PINMODE_ADC;
        config[p].adcsamp = s;
    }

    else if( !strcmp(argv[2], "pwm") ){
        if( descr[p].timer == -1 ){
            fprintf(STDERR, "pwm not supported on pin %s\n", argv[1]);
            return 0;
        }
        short m = GPIO_AF( descr[p].timeraf ) | GPIO_PUSH_PULL | GPIO_SPEED_25MHZ;
        short v = 255;
        int   f = 10000;
        short c;

        for(c=3; c<argc-1; c++){
            if( !strcmp(argv[c], "freq") ) f = atoi(argv[c+1]);
            if( !strcmp(argv[c], "max") )  v = atoi(argv[c+1]);
        }

        gpio_init( descr[p].gpio,  m );
        pwm_init(  descr[p].timer, f, v );
        config[p].mode = PINMODE_PWM;
        config[p].pwmfreq = f;
        config[p].pwmmax  = v;
    }

    else{
        fprintf(STDERR, "invalid mode\n");
    }

    return 0;

}
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

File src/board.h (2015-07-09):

/*
  Copyright (c) 2015
  Author: Jeff Weisberg <jaw @ tcp4me.com>
  Created: 2015-Apr-02 21:37 (EDT)
  Function: 

*/

#define I2CUNIT			0

#define HWCF_GPIO_BUTTON        GPIO_C13
#define HWCF_GPIO_DPY_CD        GPIO_B10
#define HWCF_GPIO_DPY_CS        GPIO_B12
#define HWCF_GPIO_SD_CS         GPIO_A8
#define HWCF_GPIO_SD_DET        GPIO_A15
#define HWCF_GPIO_NPWREN	GPIO_B5
#define HWCF_GPIO_IMUINT	GPIO_B4		// on v1 only
#define HWCF_GPIO_NRST2		GPIO_B3		// on v2

#define HWCF_GPIO_LED_WHITE     GPIO_B8
#define HWCF_GPIO_AUDIO         GPIO_B9

#define HWCF_TIMER_LED_WHITE    TIMER_4_3
#define HWCF_TIMER_AUDIO        TIMER_4_4


#if defined(AMIKETO_v1) || defined(AMIKETO_v2)
# define HAVE_LIS3DH
#else
# define HAVE_LSM303D
#endif

#if defined(AMIKETO_v2)
// no charger or fuel gauge
#else
# define HAVE_PMIC
#endif

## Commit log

2015-03-10 replace charger
    [mini32.brd, mini32.sch]
2015-03-14 embiggen connectors
    [mini32.brd, mini32.sch]
2015-03-14 8pin dpy
    [mini32.brd, mini32.sch]
2015-03-19 sharp display
    [epaper.brd, epaper.sch]
2015-04-04 fix vreg
    [mini32.brd, mini32.sch]
2015-04-07 silk text
    [epaper.brd, epaper.sch, mini32.brd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]
2015-04-12 add p-mosfet on sd+dpy power
    [mini32.brd, mini32.sch]
2015-04-12 move vias
    [mini32.brd]
2015-04-12 cap on vbat
    [mini32.brd, mini32.sch]
2015-04-13 ground pad
    [mini32.brd, mini32.sch]
2015-04-13 rename files
    [amiketo.brd, amiketo.sch]
2015-04-17 adc samples
2015-04-18 lis3dh accel
    [amiketo.brd, amiketo.sch]
2015-04-18 move usb, embiggen sd
    [amiketo.brd, amiketo.sch]
2015-04-18 22pin connector
    [amiketo.brd, amiketo.sch]
2015-04-19 tweak, silk
    [amiketo.brd, amiketo.sch]
2015-04-21 i2c r, tweak
    [amiketo.brd, amiketo.sch]
2015-04-24 swap regulator
    [amiketo.brd, amiketo.sch]
2015-04-26 tweak size
    [usb3.brd, usb3.sch]
2015-04-26 w/o vreg
    [usb5.brd, usb5.sch]
2015-04-26 embiggen connector
    [epaper.brd, epaper.sch, oled.brd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]
2015-04-26 display reset
    [amiketo.brd, amiketo.sch]
2015-05-09 use dma
2015-05-14 tweak silk
    [amiketo.brd, amiketo.sch, oled2.brd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]
2015-07-07 half-sized board
    [amiketo_2hm.brd, amiketo_2hm.sch]
2015-07-22 scootch closer to edge
    [oledrgb.brd]
2015-07-22 add info
    [amiketo.sch]
2015-10-02 power ckt
    [amiketo_2hm.brd, amiketo_2hm.sch]

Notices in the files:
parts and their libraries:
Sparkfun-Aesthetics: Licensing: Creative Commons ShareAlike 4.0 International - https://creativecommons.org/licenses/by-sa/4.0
